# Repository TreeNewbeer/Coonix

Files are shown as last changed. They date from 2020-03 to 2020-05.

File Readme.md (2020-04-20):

# Coonix

_Coonix_ is a funny project about building a application platform in Allwinner-v3s processor or nuvoton nuc980 processor.

### The structure of _Coonix_ is shown as follow:
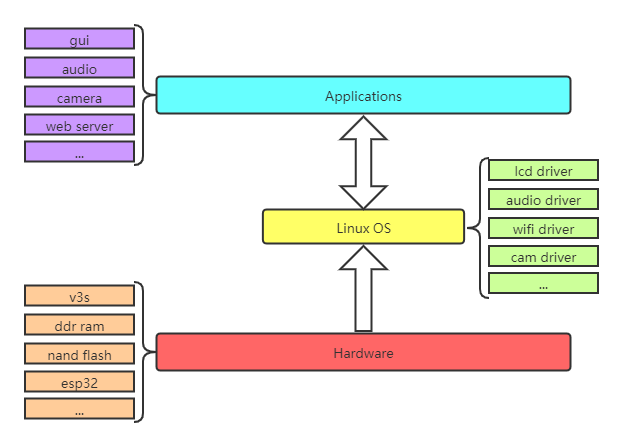
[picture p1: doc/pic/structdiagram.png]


## How to use
* TODO

## TODO
* Hardware schematic diagram
* Linux porting

## License

* MIT License

## Contributing

If you are pleased with this project, give me _Star_ rather than coffee:)

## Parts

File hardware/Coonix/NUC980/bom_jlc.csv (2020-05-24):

Comment | Description | Designator | Footprint | LibRef | Pins | Quantity
IP101GR | U202 | U202 | Package_DFN_QFN:QFN-32-1EP_4x4mm_P0.4mm_EP2.65x2.65mm |  | 2 | 1
8P8C_LED_Shielded | J201 | J201 | Connector_RJ:RJ45_Amphenol_RJHSE538X |  | 2 | 1
5.1K | R202 | R202 | 0603 |  | 2 | 1
330R | R201 | R201 | 0603 |  | 2 | 1
5.1K | R203 | R203 | 0603 |  | 2 | 1
330R | R204 | R204 | 0603 |  | 2 | 1
PT61017PEL | TR201 | TR201 | Transformer_SMD:Transformer_Ethernet_Bourns_PT61017PEL |  | 2 | 1
75R | R207 | R207 | 0603 |  | 2 | 1
75R | R208 | R208 | 0603 |  | 2 | 1
75R | R210 | R210 | 0603 |  | 2 | 1
75R | R209 | R209 | 0603 |  | 2 | 1
0.01uF/2KV | C201 | C201 | Capacitor_SMD:C_1812_4532Metric |  | 2 | 1
0.01uF | C203 | C203 | 0603 |  | 2 | 1
0.1uF | C204 | C204 | 0603 |  | 2 | 1
0.01uF | C205 | C205 | 0603 |  | 2 | 1
0.1uF | C206 | C206 | 0603 |  | 2 | 1
0.01uF/2KV | C202 | C202 | Capacitor_SMD:C_1812_4532Metric |  | 2 | 1
120R | FB202 | FB202 | 0805 |  | 2 | 1
0.1uF | C213 | C213 | 0603 |  | 2 | 1
10uF | C211 | C211 | 0805 |  | 2 | 1
120R | FB201 | FB201 | 0805 |  | 2 | 1
0.1uF | C212 | C212 | 0603 |  | 2 | 1
10uF | C210 | C210 | 0805 |  | 2 | 1
25MHz | Y201 | Y201 | Crystal:Crystal_SMD_3225-4Pin_3.2x2.5mm |  | 2 | 1
1M | R216 | R216 | 0603 |  | 2 | 1
30pF | C209 | C209 | 0603 |  | 2 | 1
30pF | C214 | C214 | 0603 |  | 2 | 1
0R | R206 | R206 | 0603 |  | 2 | 1
0.01uF | C207 | C207 | 0603 |  | 2 | 1
0.1uF | C208 | C208 | 0603 |  | 2 | 1
6.19K | R215 | R215 | 0603 |  | 2 | 1
5.1K | R212 | R212 | 0603 |  | 2 | 1
5.1K | R213 | R213 | 0603 |  | 2 | 1
5.1K | R214 | R214 | 0603 |  | 2 | 1
10K | R211 | R211 | 0603 |  | 2 | 1
10K | R205 | R205 | 0603 |  | 2 | 1
USB_A | J301 | J301 | Connector_USB:USB_A_Stewart_SS-52100-001_Horizontal |  | 2 | 1
USB_C_Receptacle | J302 | J302 | Connector_USB:USB_C_Receptacle_Palconn_UTC16-G |  | 2 | 1
0.01uF | C303 | C303 | 0603 |  | 2 | 1
22R | R303 | R303 | 0603 |  | 2 | 1
22R | R304 | R304 | 0603 |  | 2 | 1
0.01uF | C304 | C304 | 0603 |  | 2 | 1
22R | R301 | R301 | 0603 |  | 2 | 1
22R | R302 | R302 | 0603 |  | 2 | 1
5.1K | R305 | R305 | 0603 |  | 2 | 1
5.1K | R306 | R306 | 0603 |  | 2 | 1
USB0 Host/Device | JP301 | JP301 | Jumper:SolderJumper-2_P1.3mm_Open_Pad1.0x1.5mm |  | 2 | 1
10uF | C301 | C301 | 0805 |  | 2 | 1
10uF | C302 | C302 | 0805 |  | 2 | 1
20K | R308 | R308 | 0603 |  | 2 | 1
39K | R309 | R309 | 0603 |  | 2 | 1
POWER | J303 | J303 | Connector_Phoenix_MC_HighVoltage:PhoenixContact_MC_1,5_2-G-5.08_1x02_P5.08mm_Horizontal |  | 2 | 1
SS14 | D302 | D302 | Diode_SMD:D_SMA |  | 2 | 1
10uF | C306 | C306 | 0805 |  | 2 | 1
0.1uF | C305 | C305 | 0603 |  | 2 | 1
10K | R307 | R307 | 0603 |  | 2 | 1
GREEN | D301 | D301 | LED_SMD:LED_0603_1608Metric |  | 2 | 1
MountingHole | H301 | H301 | MountingHole:MountingHole_3.2mm_M3_Pad_Via |  | 2 | 1
MountingHole | H302 | H302 | MountingHole:MountingHole_3.2mm_M3_Pad_Via |  | 2 | 1
MountingHole | H303 | H303 | MountingHole:MountingHole_3.2mm_M3_Pad_Via |  | 2 | 1
MountingHole | H304 | H304 | MountingHole:MountingHole_3.2mm_M3_Pad_Via |  | 2 | 1
W25N01GV | U401 | U401 | MicroSD:Mi |  | 2 | 1
10uF | C401 | C401 | 0805 |  | 2 | 1
0.1uF | C402 | C402 | 0603 |  | 2 | 1
0R | R401 | R401 | 0603 |  | 2 | 1
10Kx4 | RN401 | RN401 | Resistor_SMD:R_Array_Convex_4x0603 |  | 2 | 1
0R | R501 | R501 | 0603 |  | 2 | 1
120R | FB501 | FB501 | 0805 |  | 2 | 1
0.1uF | C501 | C501 | 0603 |  | 2 | 1
10uF | C502 | C502 | 0805 |  | 2 | 1
Micro_SD_Card | J501 | J501 | MicroSD:MicroSD |  | 2 | 1
10Kx4 | RN501 | RN501 | Resistor_SMD:R_Array_Convex_4x0603 |  | 2 | 1
10Kx4 | RN502 | RN502 | Resistor_SMD:R_Array_Convex_4x0603 |  | 2 | 1
Conn_01x10 | J601 | J601 | Connector_Molex:Molex_PicoBlade_53048-1010_1x10_P1.25mm_Horizontal |  | 2 | 1
NUC980DK | U201 | U201 | Package_QFP:LQFP-128_14x14mm_P0.4mm |  | 2 | 1
JTAG | J702 | J702 | Connector_Molex:Molex_PicoBlade_53048-0810_1x08_P1.25mm_Horizontal |  | 2 | 1
0R | R704 | R704 | 0603 |  | 2 | 1
10Kx4 | RN701 | RN701 | Resistor_SMD:R_Array_Convex_4x0603 |  | 2 | 1
EA3036 | U701 | U701 | Package_DFN_QFN:QFN-20-1EP_3x3mm_P0.4mm_EP1.65x1.65mm |  | 2 | 1
2.2uH 1.5A | L701 | L701 | Inductor_SMD:L_Taiyo-Yuden_NR-30xx |  | 2 | 1
100K | R707 | R707 | 0603 |  | 2 | 1
10uF | C740 | C740 | 0805 |  | 2 | 1
100K | R708 | R708 | 0603 |  | 2 | 1
18pF | C732 | C732 | 0603 |  | 2 | 1
2.2uH 1.5A | L702 | L702 | Inductor_SMD:L_Taiyo-Yuden_NR-30xx |  | 2 | 1
200K | R709 | R709 | 0603 |  | 2 | 1
10uF | C741 | C741 | 0805 |  | 2 | 1
100K | R710 | R710 | 0603 |  | 2 | 1
18pF | C733 | C733 | 0603 |  | 2 | 1
2.2uH 1.5A | L703 | L703 | Inductor_SMD:L_Taiyo-Yuden_NR-30xx |  | 2 | 1
68K | R711 | R711 | 0603 |  | 2 | 1
10uF | C742 | C742 | 0805 |  | 2 | 1
15K | R712 | R712 | 0603 |  | 2 | 1
18pF | C734 | C734 | 0603 |  | 2 | 1
10uF | C707 | C707 | 0805 |  | 2 | 1
10uF | C708 | C708 | 0805 |  | 2 | 1
10uF | C710 | C710 | 0805 |  | 2 | 1
1uF | C712 | C712 | 0603 |  | 2 | 1
0.1uF | C718 | C718 | 0603 |  | 2 | 1
0.1uF | C720 | C720 | 0603 |  | 2 | 1
0.1uF | C722 | C722 | 0603 |  | 2 | 1
0.1uF | C724 | C724 | 0603 |  | 2 | 1
0.1uF | C726 | C726 | 0603 |  | 2 | 1
0.1uF | C728 | C728 | 0603 |  | 2 | 1
0.1uF | C729 | C729 | 0603 |  | 2 | 1
10uF | C730 | C730 | 0805 |  | 2 | 1
0.1uF | C737 | C737 | 0603 |  | 2 | 1
10uF | C739 | C739 | 0805 |  | 2 | 1
120R | FB705 | FB705 | 0805 |  | 2 | 1
120R | FB703 | FB703 | 0805 |  | 2 | 1
0R | R713 | R713 | 0603 |  | 2 | 1
0.1uF | C711 | C711 | 0603 |  | 2 | 1
0.1uF | C713 | C713 | 0603 |  | 2 | 1
0.1uF | C714 | C714 | 0603 |  | 2 | 1
0.1uF | C715 | C715 | 0603 |  | 2 | 1
0.1uF | C716 | C716 | 0603 |  | 2 | 1
0.1uF | C717 | C717 | 0603 |  | 2 | 1
10uF | C721 | C721 | 0805 |  | 2 | 1
120R | FB702 | FB702 | 0805 |  | 2 | 1
10uF | C719 | C719 | 0805 |  | 2 | 1
10uF | C723 | C723 | 0805 |  | 2 | 1
10uF | C725 | C725 | 0805 |  | 2 | 1
10uF | C727 | C727 | 0805 |  | 2 | 1
120R | FB704 | FB704 | 0805 |  | 2 | 1
0.1uF | C731 | C731 | 0603 |  | 2 | 1
0.1uF | C735 | C735 | 0603 |  | 2 | 1
10uF | C738 | C738 | 0805 |  | 2 | 1
10uF | C736 | C736 | 0805 |  | 2 | 1
1uF | C706 | C706 | 0603 |  | 2 | 1
100K | R705 | R705 | 0603 |  | 2 | 1
MMBT3904 | Q701 | Q701 | Package_TO_SOT_SMD:SOT-23 |  | 2 | 1
1uF | C709 | C709 | 0603 |  | 2 | 1
100K | R706 | R706 | 0603 |  | 2 | 1
RESET | SW701 | SW701 | Button_Switch_SMD:SW_DIP_SPSTx01_Slide_Copal_CHS-01A_W5.08mm_P1.27mm_JPin |  | 2 | 1
470R | R701 | R701 | 0603 |  | 2 | 1
1nF | C703 | C703 | 0603 |  | 2 | 1
120R | FB701 | FB701 | 0805 |  | 2 | 1
12MHz | Y702 | Y702 | Crystal:Crystal_SMD_3225-4Pin_3.2x2.5mm |  | 2 | 1
15pF | C704 | C704 | 0603 |  | 2 | 1
15pF | C705 | C705 | 0603 |  | 2 | 1
32.768KHz | Y701 | Y701 | Crystal:Crystal_DS26_D2.0mm_L6.0mm_Horizontal |  | 2 | 1
15pF | C701 | C701 | 0603 |  | 2 | 1
15pF | C702 | C702 | 0603 |  | 2 | 1
12.1K | R703 | R703 | 0603 |  | 2 | 1
12.1K | R702 | R702 | 0603 |  | 2 | 1
Debug_UART | J701 | J701 | Connector_PinSocket_2.54mm:PinSocket_1x03_P2.54mm_Vertical |  | 2 | 1
NC | R719 | R719 | 0603 |  | 2 | 1
NC | R720 | R720 | 0603 |  | 2 | 1
NC | R721 | R721 | 0603 |  | 2 | 1
SW_DIP_x04 | SW702 | SW702 | Button_Switch_THT:SW_DIP_SPSTx04_Piano_10.8x11.72mm_W7.62mm_P2.54mm |  | 2 | 1
NC | R718 | R718 | 0603 |  | 2 | 1
AC1583 | J801 | J801 | Connector_PinHeader_2.54mm:PinHeader_2x20_P2.54mm_Vertical |  | 2 | 1
Conn_01x10 | J901 | J901 | Connector_Molex:Molex_PicoBlade_53048-1010_1x10_P1.25mm_Horizontal |  | 2 | 1
MAX485E | U1001 | U1001 | Package_SO:SOIC-8_3.9x4.9mm_P1.27mm |  | 2 | 1
0.1uF | C1001 | C1001 | 0603 |  | 2 | 1
Conn_01x05 | J1001 | J1001 | Connector_Phoenix_MC:PhoenixContact_MC_1,5_5-G-3.81_1x05_P3.81mm_Horizontal |  | 2 | 1
120R | R1001 | R1001 | 0603 |  | 2 | 1
JP | JP1001 | JP1001 | Jumper:SolderJumper-2_P1.3mm_Open_Pad1.0x1.5mm |  | 2 | 1
SN65HVD232 | U1101 | U1101 | Package_SO:SOIC-8_3.9x4.9mm_P1.27mm |  | 2 | 1
0.1uF | C1101 | C1101 | 0603 |  | 2 | 1
Conn_01x02 | J1101 | J1101 | Connector_Phoenix_MC:PhoenixContact_MC_1,5_2-G-3.81_1x02_P3.81mm_Horizontal |  | 2 | 1
120R | R1101 | R1101 | 0603 |  | 2 | 1
JP | JP1101 | JP1101 | Jumper:SolderJumper-2_P1.3mm_Open_Pad1.0x1.5mm |  | 2 | 1
GREEN | D1202 | D1202 | LED_SMD:LED_0603_1608Metric |  | 2 | 1
RED | D1201 | D1201 | LED_SMD:LED_0603_1608Metric |  | 2 | 1
SW_Push | SW1201 | SW1201 | Button_Switch_SMD:SW_DIP_SPSTx01_Slide_Copal_CHS-01A_W5.08mm_P1.27mm_JPin |  | 2 | 1
SW_Push | SW1202 | SW1202 | Button_Switch_SMD:SW_DIP_SPSTx01_Slide_Copal_CHS-01A_W5.08mm_P1.27mm_JPin |  | 2 | 1
SW_Push | SW1203 | SW1203 | Button_Switch_SMD:SW_DIP_SPSTx01_Slide_Copal_CHS-01A_W5.08mm_P1.27mm_JPin |  | 2 | 1
4.7K | R1201 | R1201 | 0603 |  | 2 | 1
4.7K | R1202 | R1202 | 0603 |  | 2 | 1
10Kx4 | RN1201 | RN1201 | Resistor_SMD:R_Array_Convex_4x0603 |  | 2 | 1

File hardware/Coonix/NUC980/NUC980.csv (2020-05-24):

Reference | Value | Footprint | Datasheet | LCCODE
U202 | IP101GR | Package_DFN_QFN:QFN-32-1EP_4x4mm_P0.4mm_EP2.65x2.65mm
J201 | 8P8C_LED_Shielded | Connector_RJ:RJ45_Amphenol_RJHSE538X | ~ | C86578
R202 | 5.1K | Resistor_SMD:R_0603_1608Metric | ~
R201 | 330R | Resistor_SMD:R_0603_1608Metric | ~
R203 | 5.1K | Resistor_SMD:R_0603_1608Metric | ~
R204 | 330R | Resistor_SMD:R_0603_1608Metric | ~
TR201 | PT61017PEL | Transformer_SMD:Transformer_Ethernet_Bourns_PT61017PEL | https://www.bourns.com/docs/Product-Datasheets/PT61017PEL.pdf
R207 | 75R | Resistor_SMD:R_0603_1608Metric | ~
R208 | 75R | Resistor_SMD:R_0603_1608Metric | ~
R210 | 75R | Resistor_SMD:R_0603_1608Metric | ~
R209 | 75R | Resistor_SMD:R_0603_1608Metric | ~
C201 | 0.01uF/2KV | Capacitor_SMD:C_1812_4532Metric | ~
C203 | 0.01uF | Capacitor_SMD:C_0603_1608Metric | ~
C204 | 0.1uF | Capacitor_SMD:C_0603_1608Metric | ~
C205 | 0.01uF | Capacitor_SMD:C_0603_1608Metric | ~
C206 | 0.1uF | Capacitor_SMD:C_0603_1608Metric | ~
C202 | 0.01uF/2KV | Capacitor_SMD:C_1812_4532Metric | ~
FB202 | 120R | Inductor_SMD:L_0805_2012Metric | ~
C213 | 0.1uF | Capacitor_SMD:C_0603_1608Metric | ~
C211 | 10uF | Capacitor_SMD:C_0805_2012Metric | ~
FB201 | 120R | Inductor_SMD:L_0805_2012Metric | ~
C212 | 0.1uF | Capacitor_SMD:C_0603_1608Metric | ~
C210 | 10uF | Capacitor_SMD:C_0805_2012Metric | ~
Y201 | 25MHz | Crystal:Crystal_SMD_3225-4Pin_3.2x2.5mm | ~
R216 | 1M | Resistor_SMD:R_0603_1608Metric | ~
C209 | 30pF | Capacitor_SMD:C_0603_1608Metric | ~
C214 | 30pF | Capacitor_SMD:C_0603_1608Metric | ~
R206 | 0R | Resistor_SMD:R_0603_1608Metric | ~
C207 | 0.01uF | Capacitor_SMD:C_0603_1608Metric | ~
C208 | 0.1uF | Capacitor_SMD:C_0603_1608Metric | ~
R215 | 6.19K | Resistor_SMD:R_0603_1608Metric | ~
R212 | 5.1K | Resistor_SMD:R_0603_1608Metric | ~
R213 | 5.1K | Resistor_SMD:R_0603_1608Metric | ~
R214 | 5.1K | Resistor_SMD:R_0603_1608Metric | ~
R211 | 10K | Resistor_SMD:R_0603_1608Metric | ~
R205 | 10K | Resistor_SMD:R_0603_1608Metric | ~
J301 | USB_A | Connector_USB:USB_A_Stewart_SS-52100-001_Horizontal | ~
J302 | USB_C_Receptacle | Connector_USB:USB_C_Receptacle_Palconn_UTC16-G | https://www.usb.org/sites/default/files/documents/usb_type-c.zip
C303 | 0.01uF | Capacitor_SMD:C_0603_1608Metric | ~
R303 | 22R | Resistor_SMD:R_0603_1608Metric | ~
R304 | 22R | Resistor_SMD:R_0603_1608Metric | ~
C304 | 0.01uF | Capacitor_SMD:C_0603_1608Metric | ~
R301 | 22R | Resistor_SMD:R_0603_1608Metric | ~
R302 | 22R | Resistor_SMD:R_0603_1608Metric | ~
R305 | 5.1K | Resistor_SMD:R_0603_1608Metric | ~
R306 | 5.1K | Resistor_SMD:R_0603_1608Metric | ~
JP301 | USB0 Host/Device | Jumper:SolderJumper-2_P1.3mm_Open_Pad1.0x1.5mm | ~
C301 | 10uF | Capacitor_SMD:C_0805_2012Metric | ~
C302 | 10uF | Capacitor_SMD:C_0805_2012Metric | ~
R308 | 20K | Resistor_SMD:R_0603_1608Metric | ~
R309 | 39K | Resistor_SMD:R_0603_1608Metric | ~
J303 | POWER | Connector_Phoenix_MC_HighVoltage:PhoenixContact_MC_1,5_2-G-5.08_1x02_P5.08mm_Horizontal | ~
D302 | SS14 | Diode_SMD:D_SMA | ~
C306 | 10uF | Capacitor_SMD:C_0805_2012Metric | ~
C305 | 0.1uF | Capacitor_SMD:C_0603_1608Metric | ~
R307 | 10K | Resistor_SMD:R_0603_1608Metric | ~
D301 | GREEN | LED_SMD:LED_0603_1608Metric | ~
H301 | MountingHole | MountingHole:MountingHole_3.2mm_M3_Pad_Via | ~
H302 | MountingHole | MountingHole:MountingHole_3.2mm_M3_Pad_Via | ~
H303 | MountingHole | MountingHole:MountingHole_3.2mm_M3_Pad_Via | ~
H304 | MountingHole | MountingHole:MountingHole_3.2mm_M3_Pad_Via | ~
U401 | W25N01GV | MicroSD:Mi | http://www.winbond.com/resource-files/w25q128jv_dtr%20revc%2003272018%20plus.pdf
C401 | 10uF | Capacitor_SMD:C_0805_2012Metric | ~
C402 | 0.1uF | Capacitor_SMD:C_0603_1608Metric | ~
R401 | 0R | Resistor_SMD:R_0603_1608Metric | ~
RN401 | 10Kx4 | Resistor_SMD:R_Array_Convex_4x0603 | ~
R501 | 0R | Resistor_SMD:R_0603_1608Metric | ~
FB501 | 120R | Inductor_SMD:L_0805_2012Metric | ~
C501 | 0.1uF | Capacitor_SMD:C_0603_1608Metric | ~
C502 | 10uF | Capacitor_SMD:C_0805_2012Metric | ~
J501 | Micro_SD_Card | MicroSD:MicroSD | http://katalog.we-online.de/em/datasheet/693072010801.pdf
RN501 | 10Kx4 | Resistor_SMD:R_Array_Convex_4x0603 | ~
RN502 | 10Kx4 | Resistor_SMD:R_Array_Convex_4x0603 | ~
J601 | Conn_01x10 | Connector_Molex:Molex_PicoBlade_53048-1010_1x10_P1.25mm_Horizontal | ~
U201 | NUC980DK | Package_QFP:LQFP-128_14x14mm_P0.4mm
J702 | JTAG | Connector_Molex:Molex_PicoBlade_53048-0810_1x08_P1.25mm_Horizontal | ~
R704 | 0R | Resistor_SMD:R_0603_1608Metric | ~
RN701 | 10Kx4 | Resistor_SMD:R_Array_Convex_4x0603 | ~
U701 | EA3036 | Package_DFN_QFN:QFN-20-1EP_3x3mm_P0.4mm_EP1.65x1.65mm
L701 | 2.2uH 1.5A | Inductor_SMD:L_Taiyo-Yuden_NR-30xx | ~
R707 | 100K | Resistor_SMD:R_0603_1608Metric | ~
C740 | 10uF | Capacitor_SMD:C_0805_2012Metric | ~
R708 | 100K | Resistor_SMD:R_0603_1608Metric | ~
C732 | 18pF | Capacitor_SMD:C_0603_1608Metric | ~
L702 | 2.2uH 1.5A | Inductor_SMD:L_Taiyo-Yuden_NR-30xx | ~
R709 | 200K | Resistor_SMD:R_0603_1608Metric | ~
C741 | 10uF | Capacitor_SMD:C_0805_2012Metric | ~
R710 | 100K | Resistor_SMD:R_0603_1608Metric | ~
C733 | 18pF | Capacitor_SMD:C_0603_1608Metric | ~
L703 | 2.2uH 1.5A | Inductor_SMD:L_Taiyo-Yuden_NR-30xx | ~
R711 | 68K | Resistor_SMD:R_0603_1608Metric | ~
C742 | 10uF | Capacitor_SMD:C_0805_2012Metric | ~
R712 | 15K | Resistor_SMD:R_0603_1608Metric | ~
C734 | 18pF | Capacitor_SMD:C_0603_1608Metric | ~
C707 | 10uF | Capacitor_SMD:C_0805_2012Metric | ~
C708 | 10uF | Capacitor_SMD:C_0805_2012Metric | ~
C710 | 10uF | Capacitor_SMD:C_0805_2012Metric | ~
C712 | 1uF | Capacitor_SMD:C_0603_1608Metric | ~
C718 | 0.1uF | Capacitor_SMD:C_0603_1608Metric | ~
C720 | 0.1uF | Capacitor_SMD:C_0603_1608Metric | ~
C722 | 0.1uF | Capacitor_SMD:C_0603_1608Metric | ~
C724 | 0.1uF | Capacitor_SMD:C_0603_1608Metric | ~
C726 | 0.1uF | Capacitor_SMD:C_0603_1608Metric | ~
C728 | 0.1uF | Capacitor_SMD:C_0603_1608Metric | ~
C729 | 0.1uF | Capacitor_SMD:C_0603_1608Metric | ~
C730 | 10uF | Capacitor_SMD:C_0805_2012Metric | ~
C737 | 0.1uF | Capacitor_SMD:C_0603_1608Metric | ~
C739 | 10uF | Capacitor_SMD:C_0805_2012Metric | ~
FB705 | 120R | Inductor_SMD:L_0805_2012Metric | ~
FB703 | 120R | Inductor_SMD:L_0805_2012Metric | ~
R713 | 0R | Resistor_SMD:R_0603_1608Metric | ~
C711 | 0.1uF | Capacitor_SMD:C_0603_1608Metric | ~
C713 | 0.1uF | Capacitor_SMD:C_0603_1608Metric | ~
C714 | 0.1uF | Capacitor_SMD:C_0603_1608Metric | ~
C715 | 0.1uF | Capacitor_SMD:C_0603_1608Metric | ~
C716 | 0.1uF | Capacitor_SMD:C_0603_1608Metric | ~
C717 | 0.1uF | Capacitor_SMD:C_0603_1608Metric | ~
C721 | 10uF | Capacitor_SMD:C_0805_2012Metric | ~
FB702 | 120R | Inductor_SMD:L_0805_2012Metric | ~
C719 | 10uF | Capacitor_SMD:C_0805_2012Metric | ~
C723 | 10uF | Capacitor_SMD:C_0805_2012Metric | ~
C725 | 10uF | Capacitor_SMD:C_0805_2012Metric | ~
C727 | 10uF | Capacitor_SMD:C_0805_2012Metric | ~
FB704 | 120R | Inductor_SMD:L_0805_2012Metric | ~
C731 | 0.1uF | Capacitor_SMD:C_0603_1608Metric | ~
C735 | 0.1uF | Capacitor_SMD:C_0603_1608Metric | ~
C738 | 10uF | Capacitor_SMD:C_0805_2012Metric | ~
C736 | 10uF | Capacitor_SMD:C_0805_2012Metric | ~
C706 | 1uF | Capacitor_SMD:C_0603_1608Metric | ~
R705 | 100K | Resistor_SMD:R_0603_1608Metric | ~
Q701 | MMBT3904 | Package_TO_SOT_SMD:SOT-23 | https://www.fairchildsemi.com/datasheets/2N/2N3904.pdf
C709 | 1uF | Capacitor_SMD:C_0603_1608Metric | ~
R706 | 100K | Resistor_SMD:R_0603_1608Metric | ~
SW701 | RESET | Button_Switch_SMD:SW_DIP_SPSTx01_Slide_Copal_CHS-01A_W5.08mm_P1.27mm_JPin | ~
R701 | 470R | Resistor_SMD:R_0603_1608Metric | ~
C703 | 1nF | Capacitor_SMD:C_0603_1608Metric | ~
FB701 | 120R | Inductor_SMD:L_0805_2012Metric | ~
Y702 | 12MHz | Crystal:Crystal_SMD_3225-4Pin_3.2x2.5mm | ~
C704 | 15pF | Capacitor_SMD:C_0603_1608Metric | ~
C705 | 15pF | Capacitor_SMD:C_0603_1608Metric | ~
Y701 | 32.768KHz | Crystal:Crystal_DS26_D2.0mm_L6.0mm_Horizontal | ~
C701 | 15pF | Capacitor_SMD:C_0603_1608Metric | ~
C702 | 15pF | Capacitor_SMD:C_0603_1608Metric | ~
R703 | 12.1K | Resistor_SMD:R_0603_1608Metric | ~
R702 | 12.1K | Resistor_SMD:R_0603_1608Metric | ~
J701 | Debug_UART | Connector_PinSocket_2.54mm:PinSocket_1x03_P2.54mm_Vertical | ~
R719 | NC | Resistor_SMD:R_0603_1608Metric | ~
R720 | NC | Resistor_SMD:R_0603_1608Metric | ~
R721 | NC | Resistor_SMD:R_0603_1608Metric | ~
SW702 | SW_DIP_x04 | Button_Switch_THT:SW_DIP_SPSTx04_Piano_10.8x11.72mm_W7.62mm_P2.54mm | ~
R718 | NC | Resistor_SMD:R_0603_1608Metric | ~
J801 | AC1583 | Connector_PinHeader_2.54mm:PinHeader_2x20_P2.54mm_Vertical | ~
J901 | Conn_01x10 | Connector_Molex:Molex_PicoBlade_53048-1010_1x10_P1.25mm_Horizontal | ~
U1001 | MAX485E | Package_SO:SOIC-8_3.9x4.9mm_P1.27mm | https://datasheets.maximintegrated.com/en/ds/MAX1487E-MAX491E.pdf
C1001 | 0.1uF | Capacitor_SMD:C_0603_1608Metric | ~
J1001 | Conn_01x05 | Connector_Phoenix_MC:PhoenixContact_MC_1,5_5-G-3.81_1x05_P3.81mm_Horizontal | ~
R1001 | 120R | Resistor_SMD:R_0603_1608Metric | ~
JP1001 | JP | Jumper:SolderJumper-2_P1.3mm_Open_Pad1.0x1.5mm | ~
U1101 | SN65HVD232 | Package_SO:SOIC-8_3.9x4.9mm_P1.27mm | http://www.ti.com/lit/ds/symlink/sn65hvd230.pdf
C1101 | 0.1uF | Capacitor_SMD:C_0603_1608Metric | ~
J1101 | Conn_01x02 | Connector_Phoenix_MC:PhoenixContact_MC_1,5_2-G-3.81_1x02_P3.81mm_Horizontal | ~
R1101 | 120R | Resistor_SMD:R_0603_1608Metric | ~
JP1101 | JP | Jumper:SolderJumper-2_P1.3mm_Open_Pad1.0x1.5mm | ~
D1202 | GREEN | LED_SMD:LED_0603_1608Metric | ~
D1201 | RED | LED_SMD:LED_0603_1608Metric | ~
SW1201 | SW_Push | Button_Switch_SMD:SW_DIP_SPSTx01_Slide_Copal_CHS-01A_W5.08mm_P1.27mm_JPin | ~
SW1202 | SW_Push | Button_Switch_SMD:SW_DIP_SPSTx01_Slide_Copal_CHS-01A_W5.08mm_P1.27mm_JPin | ~
SW1203 | SW_Push | Button_Switch_SMD:SW_DIP_SPSTx01_Slide_Copal_CHS-01A_W5.08mm_P1.27mm_JPin | ~
R1201 | 4.7K | Resistor_SMD:R_0603_1608Metric | ~
R1202 | 4.7K | Resistor_SMD:R_0603_1608Metric | ~
RN1201 | 10Kx4 | Resistor_SMD:R_Array_Convex_4x0603 | ~

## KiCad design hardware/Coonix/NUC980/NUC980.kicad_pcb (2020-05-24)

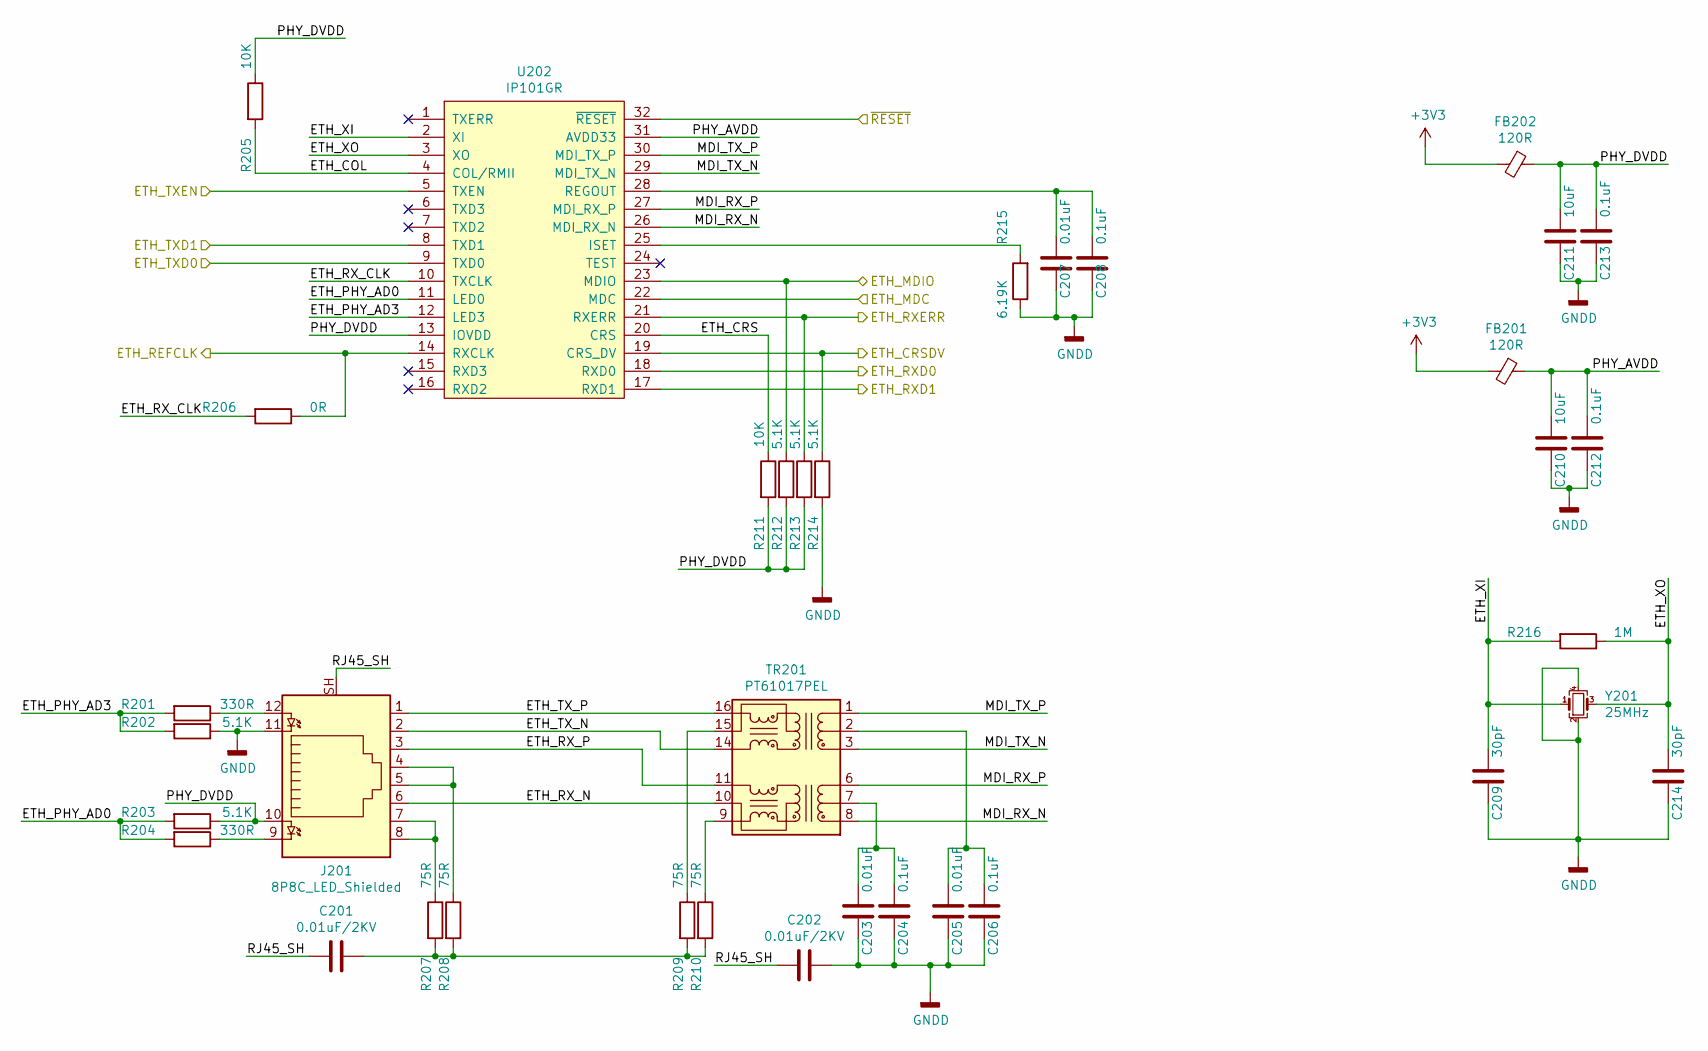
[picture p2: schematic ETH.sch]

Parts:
C201, C202: 0.01uF/2KV; C_1812_4532Metric
C203, C205, C207: 0.01uF; C_0603_1608Metric
C204, C206, C208, C212, C213: 0.1uF; C_0603_1608Metric
C209, C214: 30pF; C_0603_1608Metric
C210, C211: 10uF; C_0805_2012Metric
FB201, FB202: 120R; L_0805_2012Metric
J201: 8P8C_LED_Shielded; RJ45_Amphenol_RJHSE538X
R201, R204: 330R; R_0603_1608Metric
R202, R203, R212, R213, R214: 5.1K; R_0603_1608Metric
R205, R211: 10K; R_0603_1608Metric
R206: 0R; R_0603_1608Metric
R207, R208, R209, R210: 75R; R_0603_1608Metric
R215: 6.19K; R_0603_1608Metric
R216: 1M; R_0603_1608Metric
TR201: PT61017PEL; Transformer_Ethernet_Bourns_PT61017PEL
U202: IP101GR; QFN-32-1EP_4x4mm_P0.4mm_EP2.65x2.65mm
Y201: 25MHz; Crystal_SMD_3225-4Pin_3.2x2.5mm

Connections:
+3V3: FB201.2, FB202.2; also elsewhere on the board
/ETH/ETH_COL: R205.2, U202.4 (COL/RMII)
/ETH/ETH_CRS: R211.1, U202.20 (CRS)
/ETH/ETH_PHY_AD0: R203.2, R204.2, U202.11 (LED0)
/ETH/ETH_PHY_AD3: R201.2, R202.2, U202.12 (LED3)
/ETH/ETH_RX_CLK: R206.2, U202.10 (TXCLK)
/ETH/ETH_RX_N: J201.6, TR201.10 (C_RX)
/ETH/ETH_RX_P: J201.3, TR201.11 (RX+)
/ETH/ETH_TX_N: J201.2, TR201.14 (TX-)
/ETH/ETH_TX_P: J201.1, TR201.16 (TX+)
/ETH/ETH_XI: C209.1, R216.2, U202.2 (XI), Y201.1
/ETH/ETH_XO: C214.1, R216.1, U202.3 (XO), Y201.3
/ETH/MDI_RX_N: TR201.8 (RD-), U202.26 (MDI_RX_N)
/ETH/MDI_RX_P: TR201.6 (RD+), U202.27 (MDI_RX_P)
/ETH/MDI_TX_N: TR201.3 (TD-), U202.29 (MDI_TX_N)
/ETH/MDI_TX_P: TR201.1 (TD+), U202.30 (MDI_TX_P)
/ETH/PHY_AVDD: C210.1, C212.1, FB201.1, U202.31 (AVDD33)
/ETH/PHY_DVDD: C211.1, C213.1, FB202.1, J201.10, R203.1, R205.1, R211.2, R212.2, R213.2, U202.13 (IOVDD)
/ETH/RJ45_SH: C201.2, C202.2, J201.SH
/PE0: R213.1, U202.21 (RXERR); also elsewhere on the board
/PE1: R214.1, U202.19 (CRS_DV); also elsewhere on the board
/PE2: U202.17 (RXD1); also elsewhere on the board
/PE3: U202.18 (RXD0); also elsewhere on the board
/PE4: R206.1, U202.14 (RXCLK); also elsewhere on the board
/PE5: U202.5 (TXEN); also elsewhere on the board
/PE6: U202.8 (TXD1); also elsewhere on the board
/PE7: U202.9 (TXD0); also elsewhere on the board
/PE8: R212.1, U202.23 (MDIO); also elsewhere on the board
/PE9: U202.22 (MDC); also elsewhere on the board
/~RST: U202.32 (~RESET); also elsewhere on the board
GNDD: C202.1, C203.2, C204.2, C205.2, C206.2, C207.2, C208.2, C209.2, C210.2, C211.2, C212.2, C213.2, C214.2, J201.11, R202.1, R214.2, R215.1, Y201.2, Y201.4; also elsewhere on the board
unnamed: C201.1, R207.2, R208.2, R209.2, R210.2
unnamed: C203.1, C204.1, TR201.7 (C_RD)
unnamed: C205.1, C206.1, TR201.2 (C_TD)
unnamed: C207.1, C208.1, U202.28 (REGOUT)
unnamed: J201.4, J201.5, R208.1
unnamed: J201.7, J201.8, R207.1
unnamed: J201.9, R204.1
unnamed: J201.12, R201.1
unnamed: R209.1, TR201.15 (C_TX)
unnamed: R210.1, TR201.9 (RX-)
unnamed: R215.2, U202.25 (ISET)

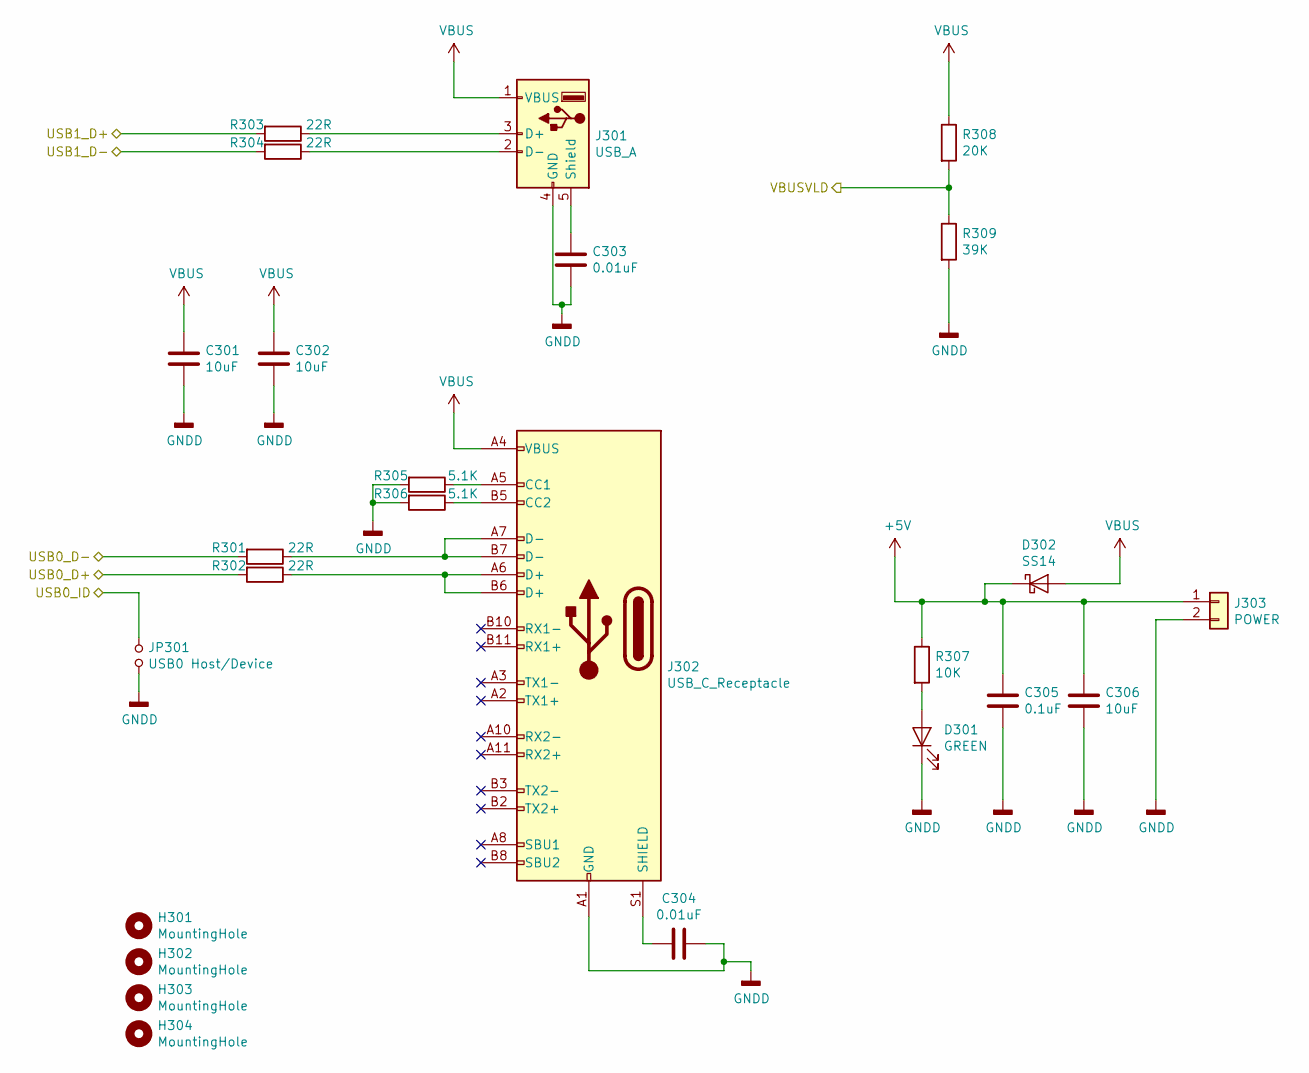
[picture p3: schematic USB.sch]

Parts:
C301, C302, C306: 10uF; C_0805_2012Metric
C303, C304: 0.01uF; C_0603_1608Metric
C305: 0.1uF; C_0603_1608Metric
D301: GREEN; LED_0603_1608Metric
D302: SS14; D_SMA
H301, H302, H303, H304: MountingHole; MountingHole_3.2mm_M3_Pad_Via
J301: USB_A; USB_A_Stewart_SS-52100-001_Horizontal
J302: USB_C_Receptacle; USB_C_Receptacle_Palconn_UTC16-G
J303: POWER; PhoenixContact_MC_1,5_2-G-5.08_1x02_P5.08mm_Horizontal
JP301: USB0 Host/Device; SolderJumper-2_P1.3mm_Open_Pad1.0x1.5mm
R301, R302, R303, R304: 22R; R_0603_1608Metric
R305, R306: 5.1K; R_0603_1608Metric
R307: 10K; R_0603_1608Metric
R308: 20K; R_0603_1608Metric
R309: 39K; R_0603_1608Metric

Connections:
+5V: C305.1, C306.1, D302.1 (K), J303.1, R307.1; also elsewhere on the board
/PE11: R308.2, R309.1; also elsewhere on the board
/USB0_D+: R302.2; also elsewhere on the board
/USB0_D-: R301.2; also elsewhere on the board
/USB0_ID: JP301.1; also elsewhere on the board
/USB1_D+: R303.2; also elsewhere on the board
/USB1_D-: R304.2; also elsewhere on the board
GNDD: C301.2, C302.2, C303.2, C304.1, C305.2, C306.2, D301.1 (K), J301.4 (GND), J302.A1 (GND), J302.A12 (GND), J302.B1 (GND), J302.B12 (GND), J303.2, JP301.2, R305.2, R306.2, R309.2; also elsewhere on the board
unnamed: C303.1, J301.5 (Shield)
unnamed: C304.2, J302.S1 (SHIELD)
unnamed: D301.2 (A), R307.2
unnamed: J301.2 (D-), R304.1
unnamed: J301.3 (D+), R303.1
unnamed: J302.A5 (CC1), R305.1
unnamed: J302.A6 (D+), J302.B6 (D+), R302.1
unnamed: J302.A7 (D-), J302.B7 (D-), R301.1
unnamed: J302.B5 (CC2), R306.1
VBUS: C301.1, C302.1, D302.2 (A), J301.1 (VBUS), J302.A4 (VBUS), J302.A9 (VBUS), J302.B4 (VBUS), J302.B9 (VBUS), R308.1

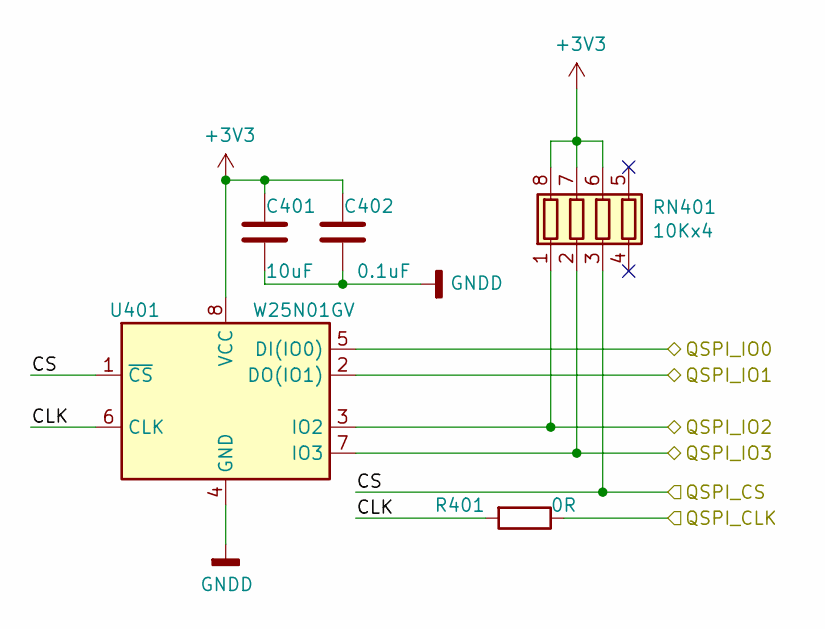
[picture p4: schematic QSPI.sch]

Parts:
C401: 10uF; C_0805_2012Metric
C402: 0.1uF; C_0603_1608Metric
R401: 0R; R_0603_1608Metric
RN401: 10Kx4; R_Array_Convex_4x0603
U401: W25N01GV; Mi

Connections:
+3V3: C401.2, C402.2, RN401.6 (R3.2), RN401.7 (R2.2), RN401.8 (R1.2), U401.8 (VCC); also elsewhere on the board
/QSPI/CLK: R401.2, U401.6 (CLK)
/QSPI_CLK: R401.1; also elsewhere on the board
/QSPI_CS: RN401.3 (R3.1), U401.1 (~CS); also elsewhere on the board
/QSPI_IO0: U401.5 (DI(IO0)); also elsewhere on the board
/QSPI_IO1: U401.2 (DO(IO1)); also elsewhere on the board
/QSPI_IO2: RN401.1 (R1.1), U401.3 (IO2); also elsewhere on the board
/QSPI_IO3: RN401.2 (R2.1), U401.7 (IO3); also elsewhere on the board
GNDD: C401.1, C402.1, U401.4 (GND); also elsewhere on the board

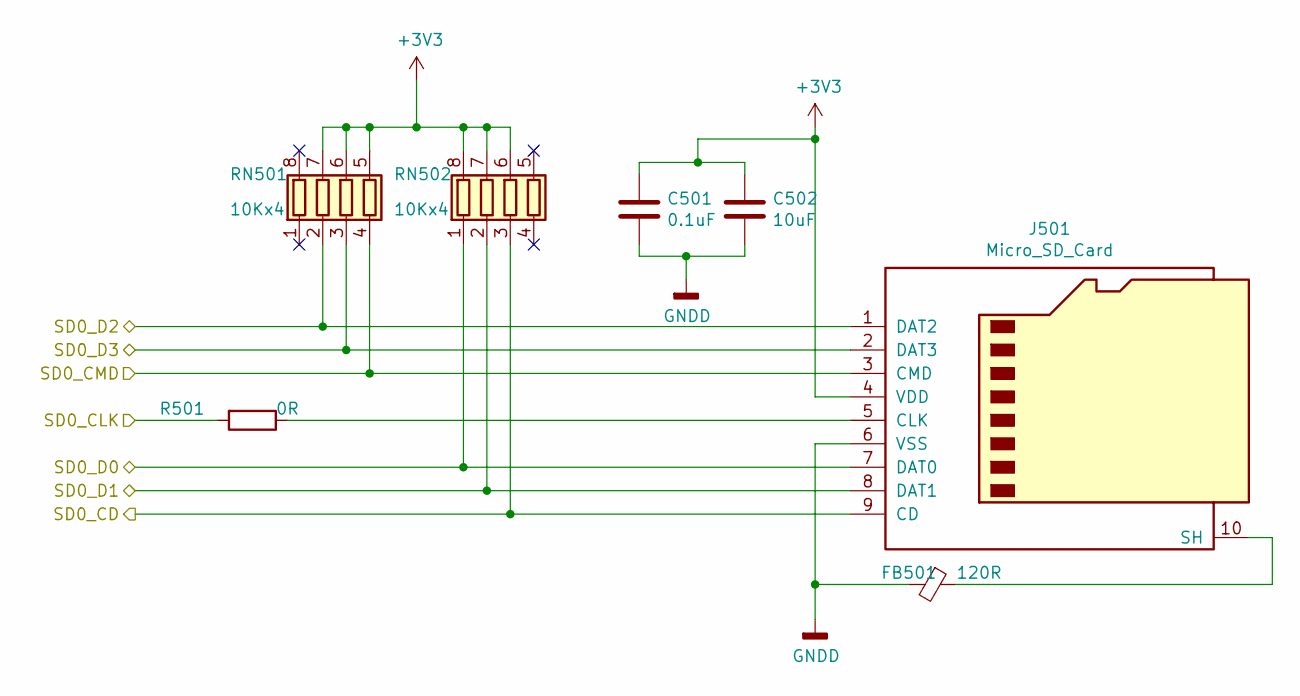
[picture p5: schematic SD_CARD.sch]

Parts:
C501: 0.1uF; C_0603_1608Metric
C502: 10uF; C_0805_2012Metric
FB501: 120R; L_0805_2012Metric
J501: Micro_SD_Card; MicroSD
R501: 0R; R_0603_1608Metric
RN501, RN502: 10Kx4; R_Array_Convex_4x0603

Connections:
+3V3: C501.1, C502.1, J501.4 (VDD), RN501.5 (R4.2), RN501.6 (R3.2), RN501.7 (R2.2), RN502.6 (R3.2), RN502.7 (R2.2), RN502.8 (R1.2); also elsewhere on the board
/SD0_CD: J501.9 (CD), RN502.3 (R3.1); also elsewhere on the board
/SD0_CLK: R501.2; also elsewhere on the board
/SD0_CMD: J501.3 (CMD), RN501.4 (R4.1); also elsewhere on the board
/SD0_D0: J501.7 (DAT0), RN502.1 (R1.1); also elsewhere on the board
/SD0_D1: J501.8 (DAT1), RN502.2 (R2.1); also elsewhere on the board
/SD0_D2: J501.1 (DAT2), RN501.2 (R2.1); also elsewhere on the board
/SD0_D3: J501.2 (DAT3), RN501.3 (R3.1); also elsewhere on the board
GNDD: C501.2, C502.2, FB501.2, J501.6 (VSS); also elsewhere on the board
unnamed: FB501.1, J501.10 (SH)
unnamed: J501.5 (CLK), R501.1

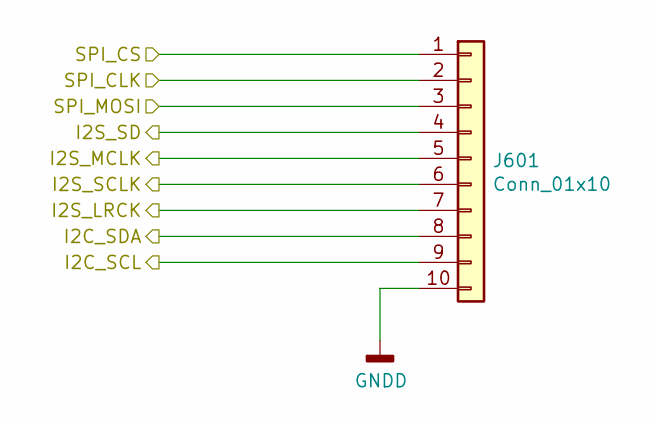
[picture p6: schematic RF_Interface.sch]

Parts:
J601: Conn_01x10; Molex_PicoBlade_53048-1010_1x10_P1.25mm_Horizontal

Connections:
/I2C0_SCL: J601.9; also elsewhere on the board
/I2C0_SDA: J601.8; also elsewhere on the board
/I2S0_BCLK: J601.6; also elsewhere on the board
/I2S0_LRCK: J601.7; also elsewhere on the board
/I2S0_MCLK: J601.5; also elsewhere on the board
/I2S0_SD: J601.4; also elsewhere on the board
/SPI1_CLK: J601.2; also elsewhere on the board
/SPI1_CS: J601.1; also elsewhere on the board
/SPI1_MOSI: J601.3; also elsewhere on the board
GNDD: J601.10; also elsewhere on the board

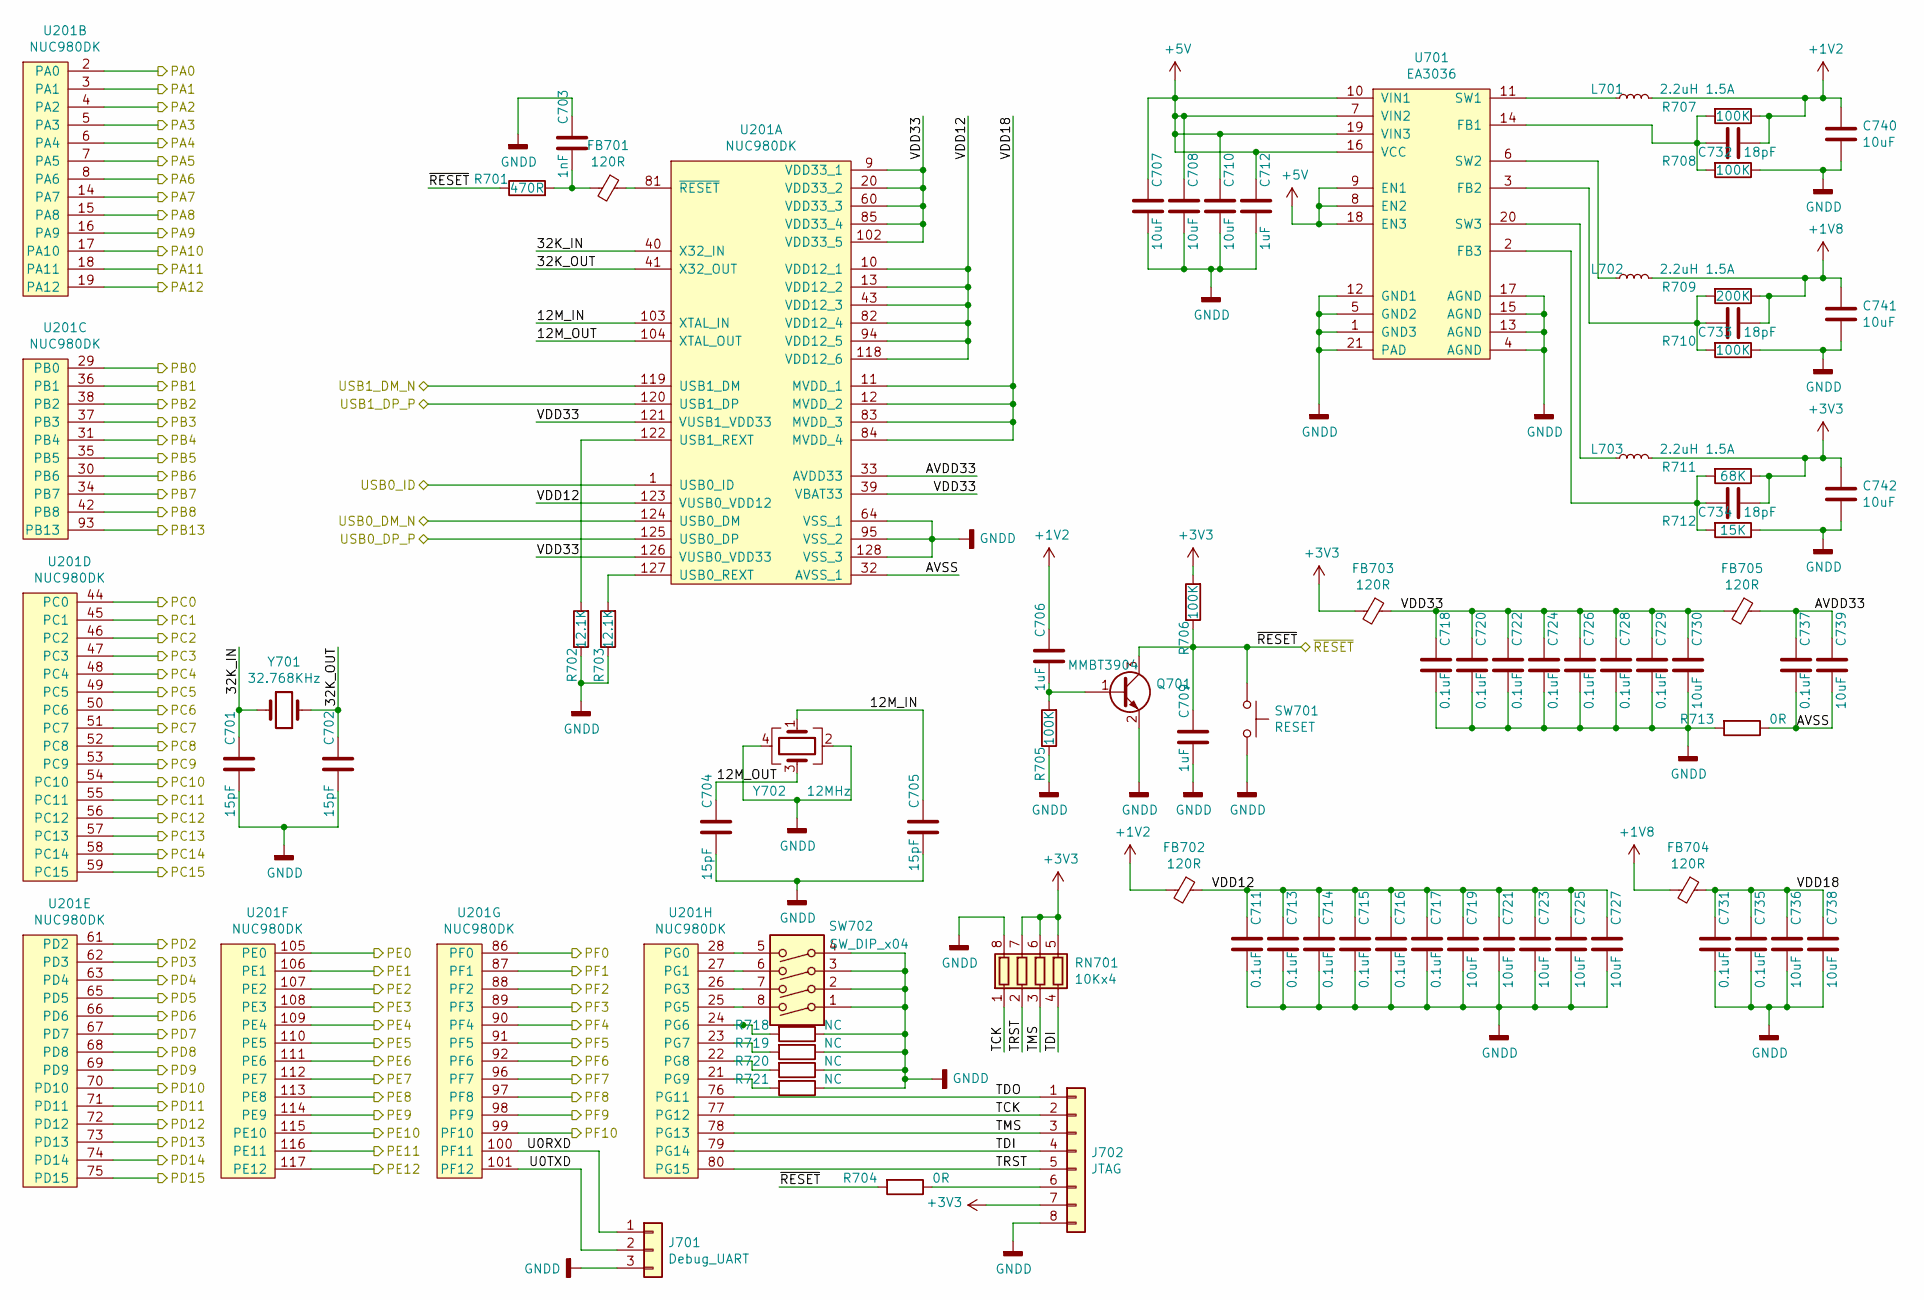
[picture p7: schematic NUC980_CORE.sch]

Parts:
C701, C702, C704, C705: 15pF; C_0603_1608Metric
C703: 1nF; C_0603_1608Metric
C706, C709, C712: 1uF; C_0603_1608Metric
C707, C708, C710, C719, C721, C723, C725, C727, C730, C736, C738, C739, C740, C741, C742: 10uF; C_0805_2012Metric
C711, C713, C714, C715, C716, C717, C718, C720, C722, C724, C726, C728, C729, C731, C735, C737: 0.1uF; C_0603_1608Metric
C732, C733, C734: 18pF; C_0603_1608Metric
FB701, FB702, FB703, FB704, FB705: 120R; L_0805_2012Metric
J701: Debug_UART; PinSocket_1x03_P2.54mm_Vertical
J702: JTAG; Molex_PicoBlade_53048-0810_1x08_P1.25mm_Horizontal
L701, L702, L703: 2.2uH 1.5A; L_Taiyo-Yuden_NR-30xx
Q701: MMBT3904; SOT-23
R701: 470R; R_0603_1608Metric
R702, R703: 12.1K; R_0603_1608Metric
R704, R713: 0R; R_0603_1608Metric
R705, R706, R707, R708, R710: 100K; R_0603_1608Metric
R709: 200K; R_0603_1608Metric
R711: 68K; R_0603_1608Metric
R712: 15K; R_0603_1608Metric
R718, R719, R720, R721: NC; R_0603_1608Metric
RN701: 10Kx4; R_Array_Convex_4x0603
SW701: RESET; SW_DIP_SPSTx01_Slide_Copal_CHS-01A_W5.08mm_P1.27mm_JPin
SW702: SW_DIP_x04; SW_DIP_SPSTx04_Piano_10.8x11.72mm_W7.62mm_P2.54mm
U201: NUC980DK; LQFP-128_14x14mm_P0.4mm
U701: EA3036; QFN-20-1EP_3x3mm_P0.4mm_EP1.65x1.65mm
Y701: 32.768KHz; Crystal_DS26_D2.0mm_L6.0mm_Horizontal
Y702: 12MHz; Crystal_SMD_3225-4Pin_3.2x2.5mm

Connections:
+1V2: C706.1, C732.1, C740.1, FB702.2, L701.2, R707.1
+1V8: C733.1, C741.1, FB704.2, L702.2, R709.1
+3V3: C734.1, C742.1, FB703.2, J702.7, L703.2, R706.2, R711.1, RN701.5 (R4.2), RN701.6 (R3.2), RN701.7 (R2.2); also elsewhere on the board
+5V: C707.1, C708.1, C710.1, C712.1, U701.7 (VIN2), U701.8 (EN2), U701.9 (EN1), U701.10 (VIN1), U701.16 (VCC), U701.18 (EN3), U701.19 (VIN3); also elsewhere on the board
/CAN1_RXD: U201.74 (PD14); also elsewhere on the board
/CAN1_TXD: U201.75 (PD15); also elsewhere on the board
/DO0: U201.96 (PF7); also elsewhere on the board
/DO1: U201.69 (PD9); also elsewhere on the board
/DO2: U201.68 (PD8); also elsewhere on the board
/I2C0_SCL: U201.3 (PA1); also elsewhere on the board
/I2C0_SDA: U201.2 (PA0); also elsewhere on the board
/I2S0_BCLK: U201.5 (PA3); also elsewhere on the board
/I2S0_LRCK: U201.4 (PA2); also elsewhere on the board
/I2S0_MCLK: U201.8 (PA6); also elsewhere on the board
/I2S0_SD: U201.6 (PA4); also elsewhere on the board
/LCD_BL: U201.18 (PA11); also elsewhere on the board
/LCD_CS: U201.16 (PA9); also elsewhere on the board
/LCD_D0: U201.44 (PC0); also elsewhere on the board
/LCD_D1: U201.45 (PC1); also elsewhere on the board
/LCD_D2: U201.46 (PC2); also elsewhere on the board
/LCD_D3: U201.47 (PC3); also elsewhere on the board
/LCD_D4: U201.48 (PC4); also elsewhere on the board
/LCD_D5: U201.49 (PC5); also elsewhere on the board
/LCD_D6: U201.50 (PC6); also elsewhere on the board
/LCD_D7: U201.51 (PC7); also elsewhere on the board
/LCD_D8: U201.52 (PC8); also elsewhere on the board
/LCD_D9: U201.53 (PC9); also elsewhere on the board
/LCD_D10: U201.54 (PC10); also elsewhere on the board
/LCD_D11: U201.55 (PC11); also elsewhere on the board
/LCD_D12: U201.56 (PC12); also elsewhere on the board
/LCD_D13: U201.57 (PC13); also elsewhere on the board
/LCD_D14: U201.58 (PC14); also elsewhere on the board
/LCD_D15: U201.59 (PC15); also elsewhere on the board
/LCD_RD: U201.15 (PA8); also elsewhere on the board
/LCD_RS: U201.17 (PA10); also elsewhere on the board
/LCD_WR: U201.14 (PA7); also elsewhere on the board
/LED/LED_G: U201.19 (PA12); also elsewhere on the board
/LED/LED_R: U201.7 (PA5); also elsewhere on the board
/NUC980_CORE/12M_IN: C705.1, U201.103 (XTAL_IN), Y702.1
/NUC980_CORE/12M_OUT: C704.1, U201.104 (XTAL_OUT), Y702.3
/NUC980_CORE/32K_IN: C701.1, U201.40 (X32_IN), Y701.1
/NUC980_CORE/32K_OUT: C702.1, U201.41 (X32_OUT), Y701.2
/NUC980_CORE/AVDD33: C737.1, C739.1, FB705.1, U201.33 (AVDD33)
/NUC980_CORE/AVSS: C737.2, C739.2, R713.1, U201.32 (AVSS_1)
/NUC980_CORE/PB0: U201.29 (PB0); also elsewhere on the board
/NUC980_CORE/PB5: U201.35 (PB5); also elsewhere on the board
/NUC980_CORE/TCK: J702.2, RN701.1 (R1.1), U201.77 (PG12)
/NUC980_CORE/TDI: J702.4, RN701.4 (R4.1), U201.79 (PG14)
/NUC980_CORE/TDO: J702.1, U201.76 (PG11)
/NUC980_CORE/TMS: J702.3, RN701.3 (R3.1), U201.78 (PG13)
/NUC980_CORE/TRST: J702.5, RN701.2 (R2.1), U201.80 (PG15)
/NUC980_CORE/U0RXD: J701.1, U201.100 (PF11)
/NUC980_CORE/U0TXD: J701.2, U201.101 (PF12)
/NUC980_CORE/VDD12: C711.1, C713.1, C714.1, C715.1, C716.1, C717.1, C719.1, C721.1, C723.1, C725.1, C727.1, FB702.1, U201.10 (VDD12_1), U201.13 (VDD12_2), U201.43 (VDD12_3), U201.82 (VDD12_4), U201.94 (VDD12_5), U201.118 (VDD12_6), U201.123 (VUSB0_VDD12)
/NUC980_CORE/VDD18: C731.1, C735.1, C736.1, C738.1, FB704.1, U201.11 (MVDD_1), U201.12 (MVDD_2), U201.83 (MVDD_3), U201.84 (MVDD_4)
/NUC980_CORE/VDD33: C718.1, C720.1, C722.1, C724.1, C726.1, C728.1, C729.1, C730.1, FB703.1, FB705.2, U201.9 (VDD33_1), U201.20 (VDD33_2), U201.39 (VBAT33), U201.60 (VDD33_3), U201.85 (VDD33_4), U201.102 (VDD33_5), U201.121 (VUSB1_VDD33), U201.126 (VUSB0_VDD33)
/PE0: U201.105 (PE0); also elsewhere on the board
/PE1: U201.106 (PE1); also elsewhere on the board
/PE2: U201.107 (PE2); also elsewhere on the board
/PE3: U201.108 (PE3); also elsewhere on the board
/PE4: U201.109 (PE4); also elsewhere on the board
/PE5: U201.110 (PE5); also elsewhere on the board
/PE6: U201.111 (PE6); also elsewhere on the board
/PE7: U201.112 (PE7); also elsewhere on the board
/PE8: U201.113 (PE8); also elsewhere on the board
/PE9: U201.114 (PE9); also elsewhere on the board
/PE11: U201.116 (PE11); also elsewhere on the board
/PWM00: U201.72 (PD12); also elsewhere on the board
/PWM01: U201.73 (PD13); also elsewhere on the board
/PWM02: U201.93 (PB13); also elsewhere on the board
/QSPI_CLK: U201.62 (PD3); also elsewhere on the board
/QSPI_CS: U201.61 (PD2); also elsewhere on the board
/QSPI_IO0: U201.63 (PD4); also elsewhere on the board
/QSPI_IO1: U201.65 (PD5); also elsewhere on the board
/QSPI_IO2: U201.66 (PD6); also elsewhere on the board
/QSPI_IO3: U201.67 (PD7); also elsewhere on the board
/SD0_CD: U201.92 (PF6); also elsewhere on the board
/SD0_CLK: U201.87 (PF1); also elsewhere on the board
/SD0_CMD: U201.86 (PF0); also elsewhere on the board
/SD0_D0: U201.88 (PF2); also elsewhere on the board
/SD0_D1: U201.89 (PF3); also elsewhere on the board
/SD0_D2: U201.90 (PF4); also elsewhere on the board
/SD0_D3: U201.91 (PF5); also elsewhere on the board
/SPI1_CLK: U201.31 (PB4); also elsewhere on the board
/SPI1_CS: U201.30 (PB6); also elsewhere on the board
/SPI1_MOSI: U201.34 (PB7); also elsewhere on the board
/TOUCH_INT: U201.38 (PB2); also elsewhere on the board
/TOUCH_SCL: U201.37 (PB3); also elsewhere on the board
/TOUCH_SDA: U201.36 (PB1); also elsewhere on the board
/U1RTS: U201.97 (PF8); also elsewhere on the board
/U1RXD: U201.98 (PF9); also elsewhere on the board
/U1TXD: U201.99 (PF10); also elsewhere on the board
/U6RXD: U201.71 (PD11); also elsewhere on the board
/U6TXD: U201.70 (PD10); also elsewhere on the board
/USB0_D+: U201.125 (USB0_DP); also elsewhere on the board
/USB0_D-: U201.124 (USB0_DM); also elsewhere on the board
/USB0_ID: U201.1 (USB0_ID); also elsewhere on the board
/USB1_D+: U201.120 (USB1_DP); also elsewhere on the board
/USB1_D-: U201.119 (USB1_DM); also elsewhere on the board
/~RST: C709.1, Q701.3 (C), R701.1, R704.2, R706.1, SW701.1; also elsewhere on the board
GNDD: C701.2, C702.2, C703.1, C704.2, C705.2, C707.2, C708.2, C709.2, C710.2, C711.2, C712.2, C713.2, C714.2, C715.2, C716.2, C717.2, C718.2, C719.2, C720.2, C721.2, C722.2, C723.2, C724.2, C725.2, C726.2, C727.2, C728.2, C729.2, C730.2, C731.2, C735.2, C736.2, C738.2, C740.2, C741.2, C742.2, J701.3, J702.8, Q701.2 (E), R702.1, R703.1, R705.1, R708.1, R710.1, R712.1, R713.2, R718.1, R719.1, R720.1, R721.1, RN701.8 (R1.2), SW701.2, SW702.1, SW702.2, SW702.3, SW702.4, U201.64 (VSS_1), U201.95 (VSS_2), U201.128 (VSS_3), U701.1 (GND3), U701.4 (AGND), U701.5 (GND2), U701.12 (GND1), U701.13 (AGND), U701.15 (AGND), U701.17 (AGND), U701.21 (PAD), Y702.2, Y702.4; also elsewhere on the board
unnamed: C703.2, FB701.2, R701.2
unnamed: C706.2, Q701.1 (B), R705.2
unnamed: C732.2, R707.2, R708.2, U701.14 (FB1)
unnamed: C733.2, R709.2, R710.2, U701.3 (FB2)
unnamed: C734.2, R711.2, R712.2, U701.2 (FB3)
unnamed: FB701.1, U201.81 (~RESET)
unnamed: J702.6, R704.1
unnamed: L701.1, U701.11 (SW1)
unnamed: L702.1, U701.6 (SW2)
unnamed: L703.1, U701.20 (SW3)
unnamed: R702.2, U201.122 (USB1_REXT)
unnamed: R703.2, U201.127 (USB0_REXT)
unnamed: R718.2, U201.24 (PG6)
unnamed: R719.2, U201.23 (PG7)
unnamed: R720.2, U201.22 (PG8)
unnamed: R721.2, U201.21 (PG9)
unnamed: SW702.5, U201.28 (PG0)
unnamed: SW702.6, U201.27 (PG1)
unnamed: SW702.7, U201.26 (PG3)
unnamed: SW702.8, U201.25 (PG5)

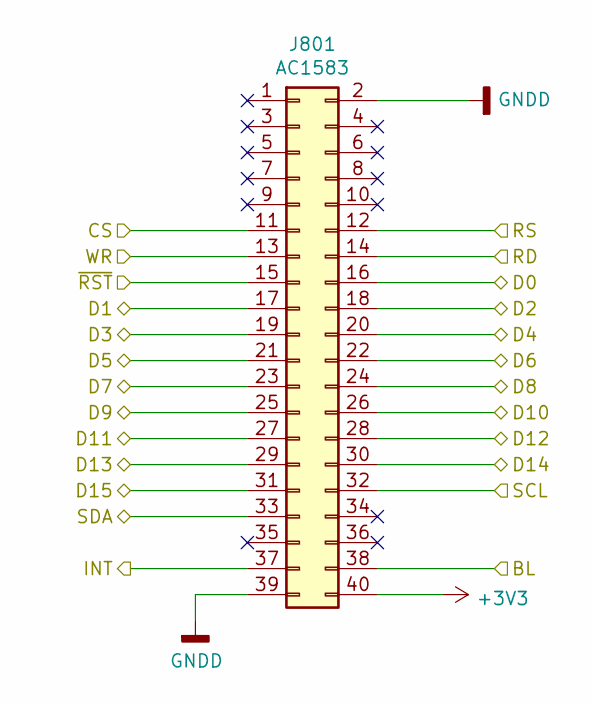
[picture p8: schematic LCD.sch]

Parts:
J801: AC1583; PinHeader_2x20_P2.54mm_Vertical

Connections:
+3V3: J801.40; also elsewhere on the board
/LCD_BL: J801.38; also elsewhere on the board
/LCD_CS: J801.11; also elsewhere on the board
/LCD_D0: J801.16; also elsewhere on the board
/LCD_D1: J801.17; also elsewhere on the board
/LCD_D2: J801.18; also elsewhere on the board
/LCD_D3: J801.19; also elsewhere on the board
/LCD_D4: J801.20; also elsewhere on the board
/LCD_D5: J801.21; also elsewhere on the board
/LCD_D6: J801.22; also elsewhere on the board
/LCD_D7: J801.23; also elsewhere on the board
/LCD_D8: J801.24; also elsewhere on the board
/LCD_D9: J801.25; also elsewhere on the board
/LCD_D10: J801.26; also elsewhere on the board
/LCD_D11: J801.27; also elsewhere on the board
/LCD_D12: J801.28; also elsewhere on the board
/LCD_D13: J801.29; also elsewhere on the board
/LCD_D14: J801.30; also elsewhere on the board
/LCD_D15: J801.31; also elsewhere on the board
/LCD_RD: J801.14; also elsewhere on the board
/LCD_RS: J801.12; also elsewhere on the board
/LCD_WR: J801.13; also elsewhere on the board
/TOUCH_INT: J801.37; also elsewhere on the board
/TOUCH_SCL: J801.32; also elsewhere on the board
/TOUCH_SDA: J801.33; also elsewhere on the board
/~RST: J801.15; also elsewhere on the board
GNDD: J801.2, J801.39; also elsewhere on the board

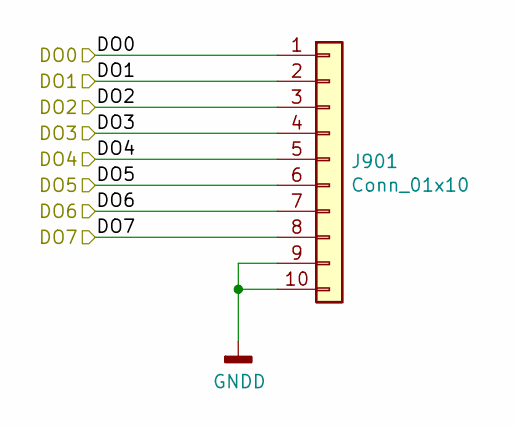
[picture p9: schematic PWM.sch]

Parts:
J901: Conn_01x10; Molex_PicoBlade_53048-1010_1x10_P1.25mm_Horizontal

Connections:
/DO0: J901.6; also elsewhere on the board
/DO1: J901.2; also elsewhere on the board
/DO2: J901.1; also elsewhere on the board
/PWM00: J901.7; also elsewhere on the board
/PWM01: J901.8; also elsewhere on the board
/PWM02: J901.3; also elsewhere on the board
GNDD: J901.9, J901.10; also elsewhere on the board

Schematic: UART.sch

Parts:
C1001: 0.1uF; C_0603_1608Metric
J1001: Conn_01x05; PhoenixContact_MC_1,5_5-G-3.81_1x05_P3.81mm_Horizontal
JP1001: JP; SolderJumper-2_P1.3mm_Open_Pad1.0x1.5mm
R1001: 120R; R_0603_1608Metric
U1001: MAX485E; SOIC-8_3.9x4.9mm_P1.27mm

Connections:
+3V3: C1001.2, U1001.8 (VCC); also elsewhere on the board
/U1RTS: U1001.2 (~RE), U1001.3 (DE); also elsewhere on the board
/U1RXD: U1001.1 (RO); also elsewhere on the board
/U1TXD: U1001.4 (DI); also elsewhere on the board
/U6RXD: J1001.3; also elsewhere on the board
/U6TXD: J1001.4; also elsewhere on the board
/UART/RS485_A: J1001.1, JP1001.2, U1001.6 (A)
/UART/RS485_B: J1001.2, R1001.2, U1001.7 (B)
GNDD: C1001.1, J1001.5, U1001.5 (GND); also elsewhere on the board
unnamed: JP1001.1, R1001.1

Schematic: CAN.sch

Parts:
C1101: 0.1uF; C_0603_1608Metric
J1101: Conn_01x02; PhoenixContact_MC_1,5_2-G-3.81_1x02_P3.81mm_Horizontal
JP1101: JP; SolderJumper-2_P1.3mm_Open_Pad1.0x1.5mm
R1101: 120R; R_0603_1608Metric
U1101: SN65HVD232; SOIC-8_3.9x4.9mm_P1.27mm

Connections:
+3V3: C1101.2, U1101.3 (VCC); also elsewhere on the board
/CAN1_RXD: U1101.4 (R); also elsewhere on the board
/CAN1_TXD: U1101.1 (D); also elsewhere on the board
GNDD: C1101.1, U1101.2 (GND); also elsewhere on the board
unnamed: J1101.1, JP1101.2, U1101.7 (CANH)
unnamed: J1101.2, R1101.2, U1101.6 (CANL)
unnamed: JP1101.1, R1101.1

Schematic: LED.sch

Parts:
D1201: RED; LED_0603_1608Metric
D1202: GREEN; LED_0603_1608Metric
R1201, R1202: 4.7K; R_0603_1608Metric
RN1201: 10Kx4; R_Array_Convex_4x0603
SW1201, SW1202, SW1203: SW_Push; SW_DIP_SPSTx01_Slide_Copal_CHS-01A_W5.08mm_P1.27mm_JPin

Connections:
+3V3: RN1201.6 (R3.2), RN1201.7 (R2.2), RN1201.8 (R1.2); also elsewhere on the board
/LED/LED_G: R1202.1; also elsewhere on the board
/LED/LED_R: R1201.1; also elsewhere on the board
/LED/SW_K3: RN1201.3 (R3.1), SW1203.2
/NUC980_CORE/PB0: RN1201.1 (R1.1), SW1201.2; also elsewhere on the board
/NUC980_CORE/PB5: RN1201.2 (R2.1), SW1202.2; also elsewhere on the board
GNDD: D1201.1 (K), D1202.1 (K), SW1201.1, SW1202.1, SW1203.1; also elsewhere on the board
unnamed: D1201.2 (A), R1201.2
unnamed: D1202.2 (A), R1202.2

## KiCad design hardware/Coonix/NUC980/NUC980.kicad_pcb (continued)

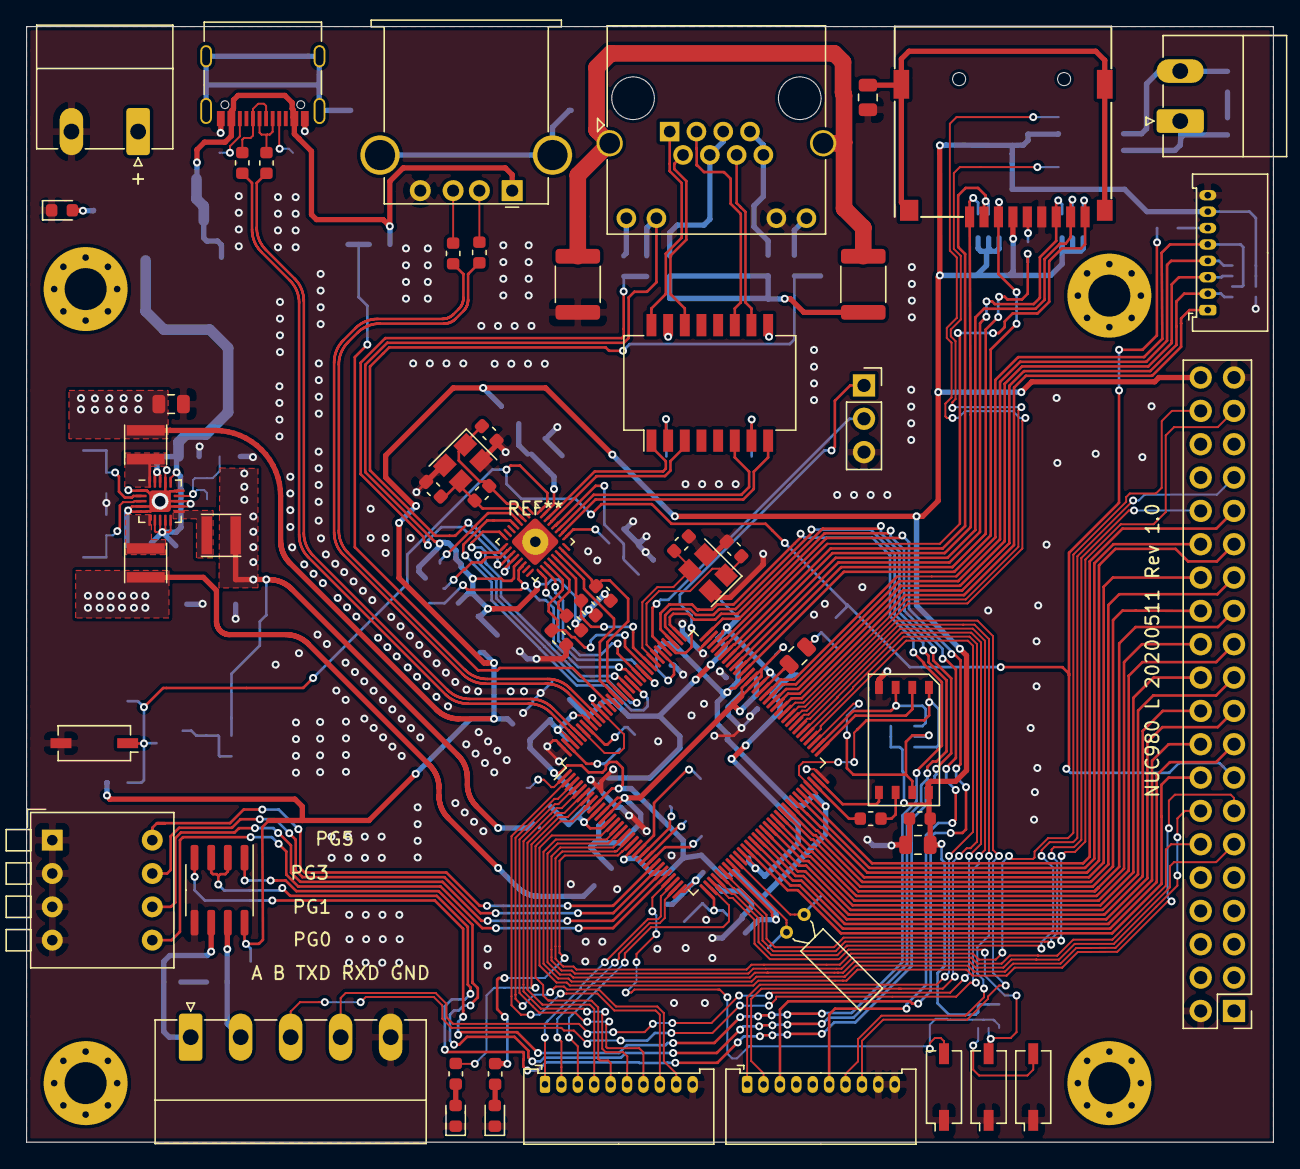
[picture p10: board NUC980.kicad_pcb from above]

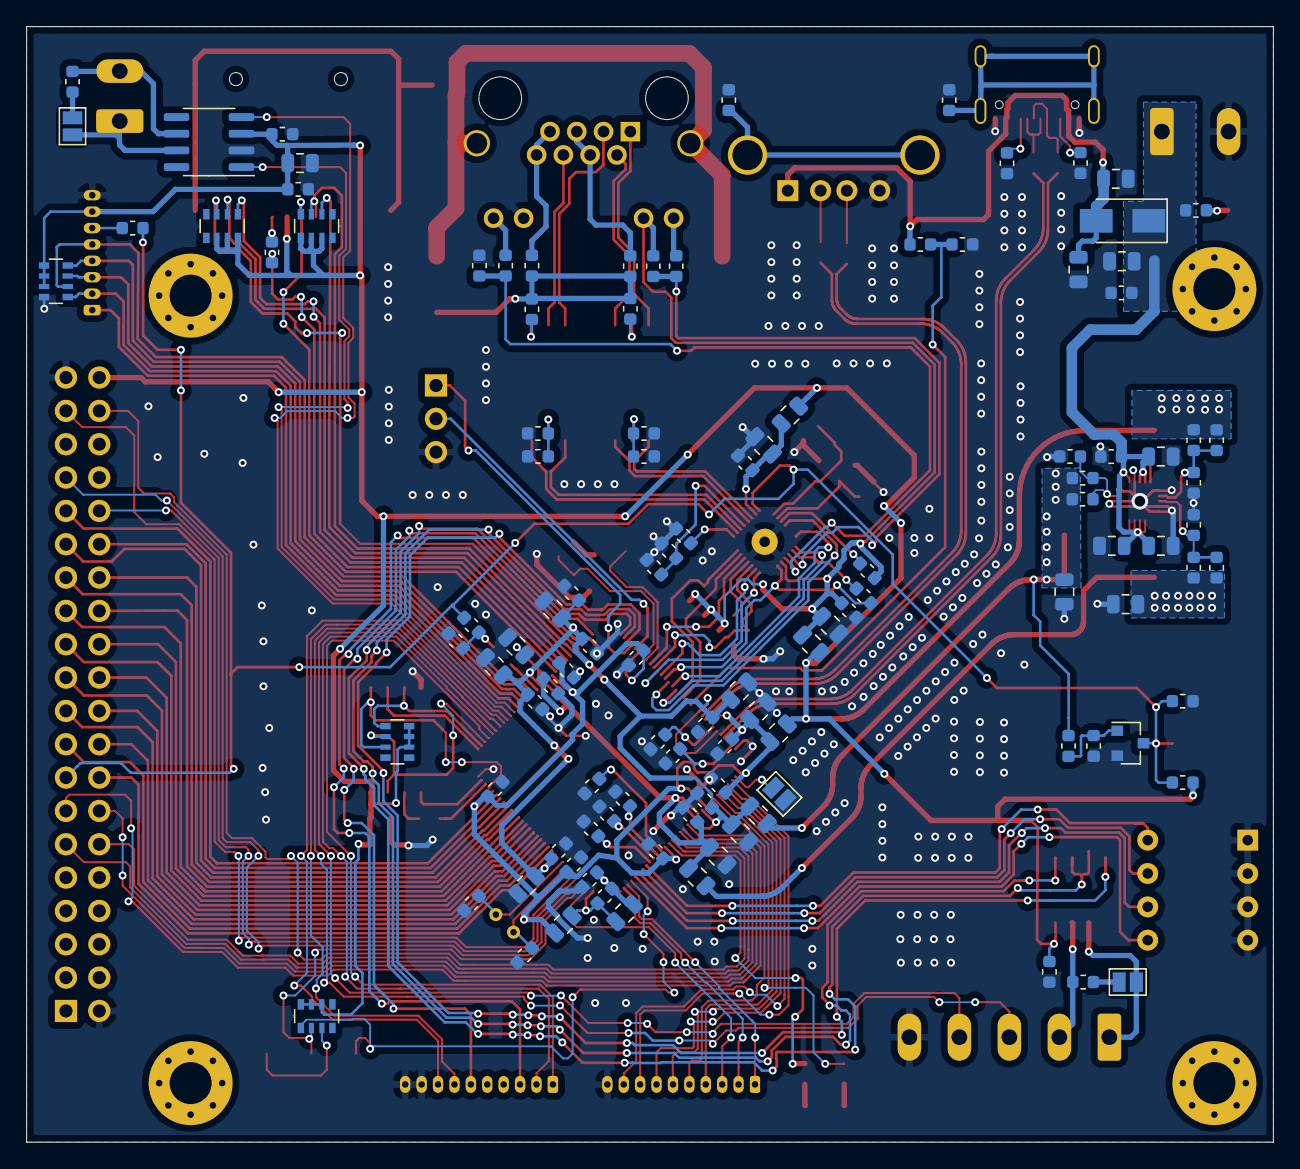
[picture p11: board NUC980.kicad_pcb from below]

Board: 2 copper layers, 95.0 x 85.0 mm, 171 parts (112 on the bottom side), 172 nets.

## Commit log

2020-04-08 feature(hardware):update V3s and EA3036 schematic symbol (issue:#1,#2)
    [Coonix.kicad_pcb, Coonix.sch]
2020-04-10 feature(hardware):update hardware schematic
    [V3s.sch, power.sch]
2020-04-20 Added something about the nuc980
    [Coonix.kicad_pcb, Coonix.sch, V3s.sch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]
2020-04-20 add nuc980 sch pcb
    [CAN.sch, ETH.sch, LCD.sch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]
2020-05-12 update pcb and add JLC STM pos, bom file
    [LCD.sch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]
